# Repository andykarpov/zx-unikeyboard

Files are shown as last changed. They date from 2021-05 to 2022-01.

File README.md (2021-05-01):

# zx-unikeyboard-ps2

This is a ps/2 keyboard controller that allows to connect any keyboard matrix and remap its keys into a ps/2 keyboard.

Based on zx-unikeyboard controller 
https://github.com/valerium-labs/zx-unikeyboard 

Based on ideas of converting a custom keyboard into PS/2-keyboard https://zx-pk.ru/threads/32497-kak-peredelat-prakticheski-lyubuyu-klaviaturu-v-ps-2.html 
and PS/2-CPLD-keyboard controller by andykarpov https://github.com/andykarpov/ps2_cpld_kbd

Unikeyboard ps/2 controller lets you connect any laptop or desktop keyboard matrix (up to 26 pins in any order), 
scan its keypresses to collect the pins interaction (AVR-Keyexplorer module), build an array of its keys and then "learn" 
a controller firmware (avr_kbd_ps2) to convert your keyboard layout into standard ps/2 keyboard.

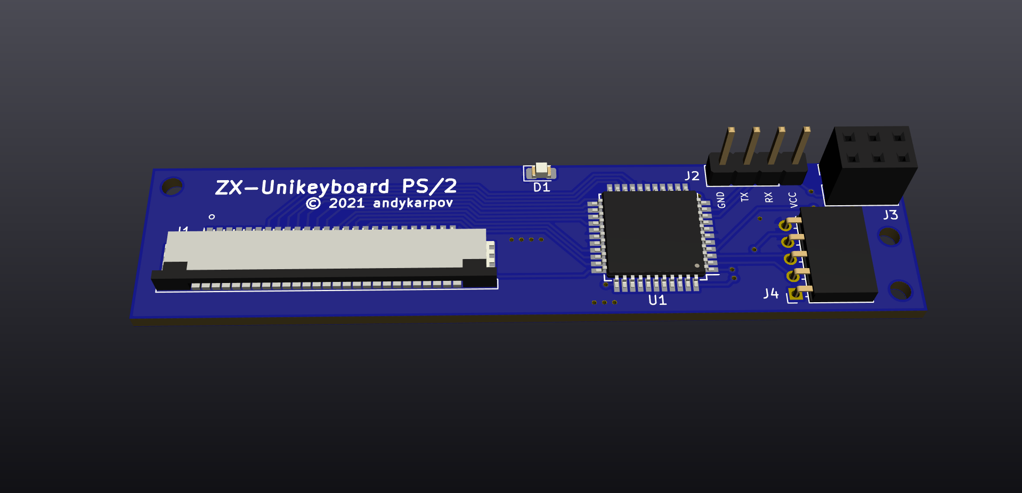
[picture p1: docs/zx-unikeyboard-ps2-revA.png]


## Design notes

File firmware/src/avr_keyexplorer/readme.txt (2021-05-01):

This is and AVR firmware source code for "Unikeyboard explorer" (keyboard matrix scanning software).
Scans any keyboard and generates the debug output on UART for col/row of key pressed.

Atmega32-16AU, 8Mhz internal clock

Designed for custom keyboard matrix by Valeriy Matveyev
valerium@rambler.ru
Russia, 2021

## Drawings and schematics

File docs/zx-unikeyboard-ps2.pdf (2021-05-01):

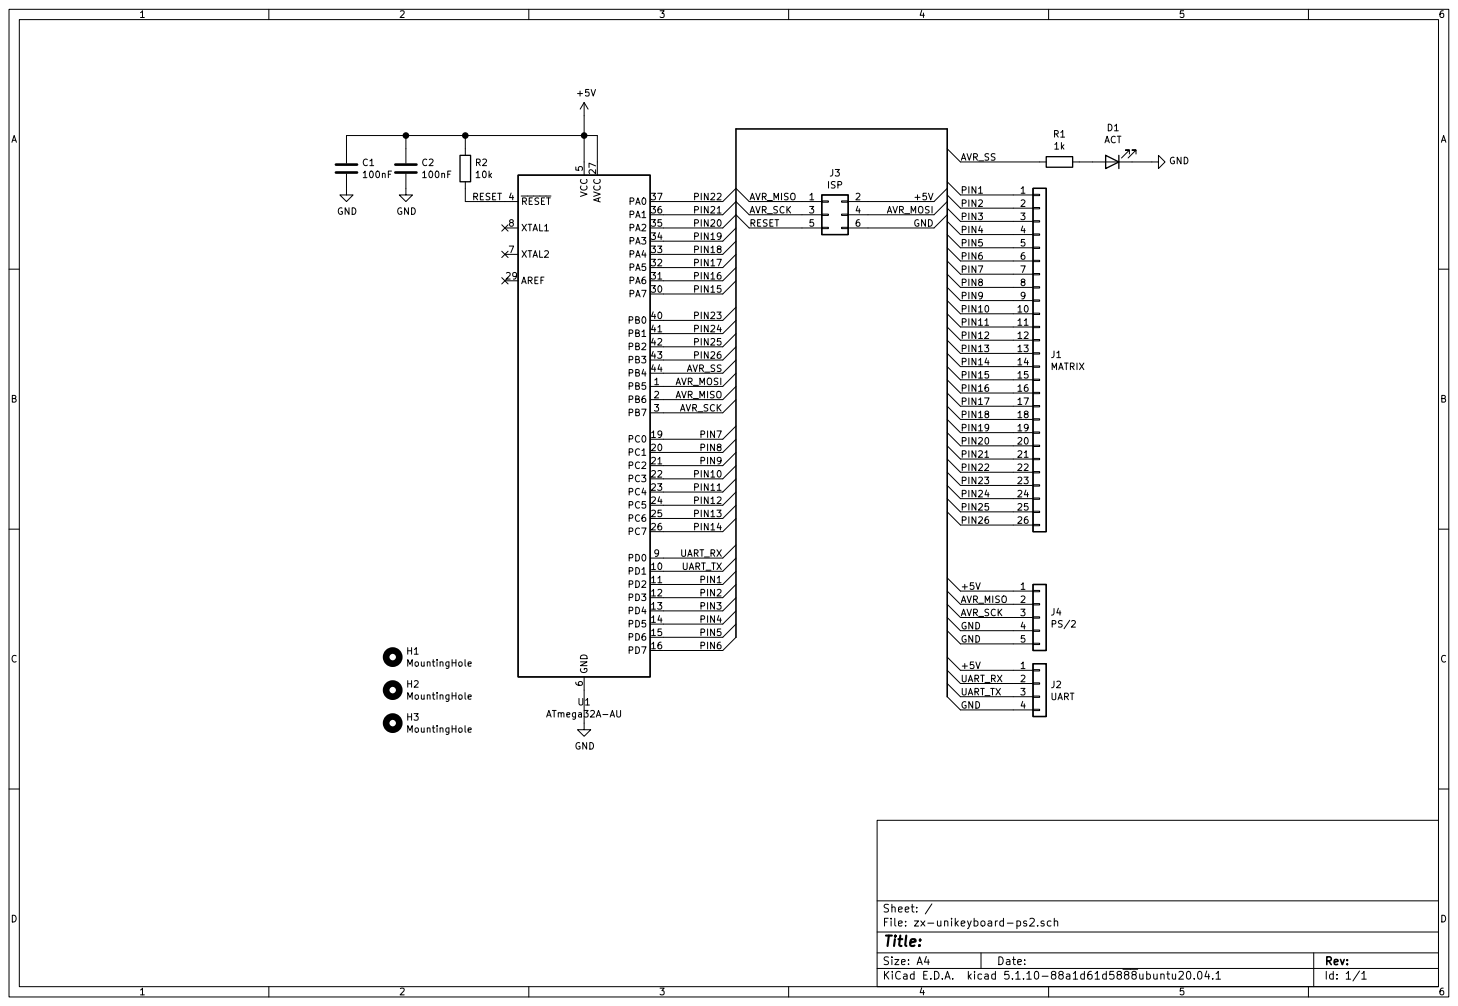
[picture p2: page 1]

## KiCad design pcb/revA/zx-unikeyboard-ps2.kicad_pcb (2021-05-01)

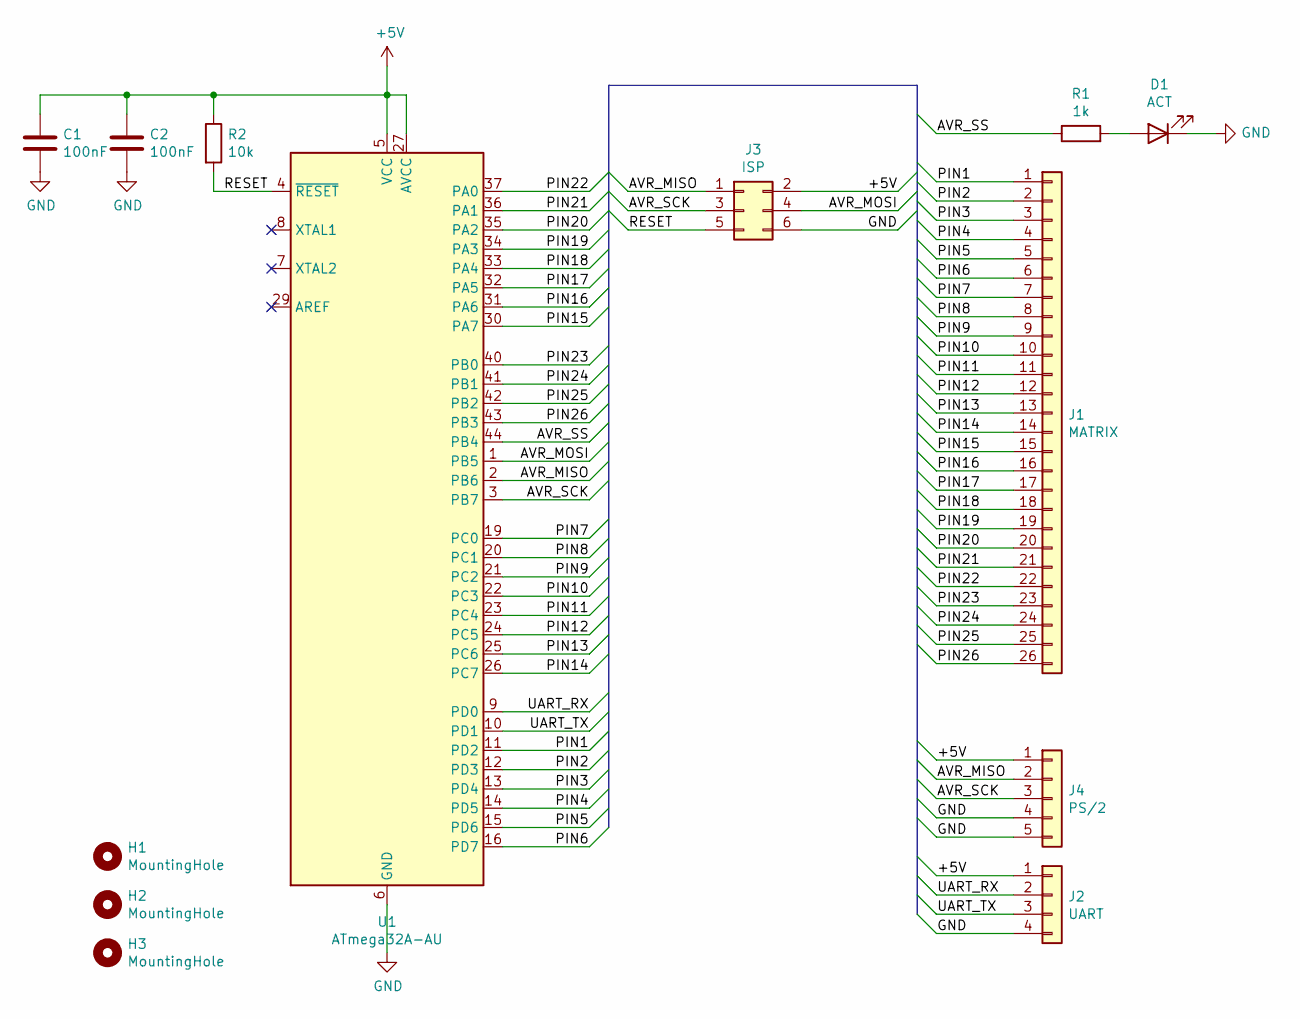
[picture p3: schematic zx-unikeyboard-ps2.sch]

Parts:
C1, C2: 100nF; C_0805_2012Metric_Pad1.18x1.45mm_HandSolder
D1: ACT; LED_0805_2012Metric_Pad1.15x1.40mm_HandSolder
H1, H2, H3: MountingHole; MountingHole_2.1mm
J1: MATRIX; TE_2-84952-6_1x26-1MP_P1.0mm_Horizontal
J2: UART; PinHeader_1x04_P2.54mm_Vertical
J3: ISP; PinSocket_2x03_P2.54mm_Vertical
J4: PS/2; JST_PH_S5B-PH-K_1x05_P2.00mm_Horizontal
R1: 1k; R_0805_2012Metric_Pad1.20x1.40mm_HandSolder
R2: 10k; R_0805_2012Metric_Pad1.20x1.40mm_HandSolder
U1: ATmega32A-AU; TQFP-44_10x10mm_P0.8mm

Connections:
+5V: C1.1, C2.1, J2.1, J3.2, J4.1, R2.1, U1.5 (VCC), U1.17 (VCC), U1.27 (AVCC), U1.38 (VCC)
/AVR_MISO: J3.1, J4.2, U1.2 (PB6)
/AVR_MOSI: J3.4, U1.1 (PB5)
/AVR_SCK: J3.3, J4.3, U1.3 (PB7)
/AVR_SS: R1.1, U1.44 (PB4)
/PIN1: J1.1, U1.11 (PD2)
/PIN2: J1.2, U1.12 (PD3)
/PIN3: J1.3, U1.13 (PD4)
/PIN4: J1.4, U1.14 (PD5)
/PIN5: J1.5, U1.15 (PD6)
/PIN6: J1.6, U1.16 (PD7)
/PIN7: J1.7, U1.19 (PC0)
/PIN8: J1.8, U1.20 (PC1)
/PIN9: J1.9, U1.21 (PC2)
/PIN10: J1.10, U1.22 (PC3)
/PIN11: J1.11, U1.23 (PC4)
/PIN12: J1.12, U1.24 (PC5)
/PIN13: J1.13, U1.25 (PC6)
/PIN14: J1.14, U1.26 (PC7)
/PIN15: J1.15, U1.30 (PA7)
/PIN16: J1.16, U1.31 (PA6)
/PIN17: J1.17, U1.32 (PA5)
/PIN18: J1.18, U1.33 (PA4)
/PIN19: J1.19, U1.34 (PA3)
/PIN20: J1.20, U1.35 (PA2)
/PIN21: J1.21, U1.36 (PA1)
/PIN22: J1.22, U1.37 (PA0)
/PIN23: J1.23, U1.40 (PB0)
/PIN24: J1.24, U1.41 (PB1)
/PIN25: J1.25, U1.42 (PB2)
/PIN26: J1.26, U1.43 (PB3)
/RESET: J3.5, R2.2, U1.4 (~RESET)
/UART_RX: J2.2, U1.9 (PD0)
/UART_TX: J2.3, U1.10 (PD1)
GND: C1.2, C2.2, D1.1 (K), J2.4, J3.6, J4.4, J4.5, U1.6 (GND), U1.18 (GND), U1.28 (GND), U1.39 (GND)
unnamed: D1.2 (A), R1.2

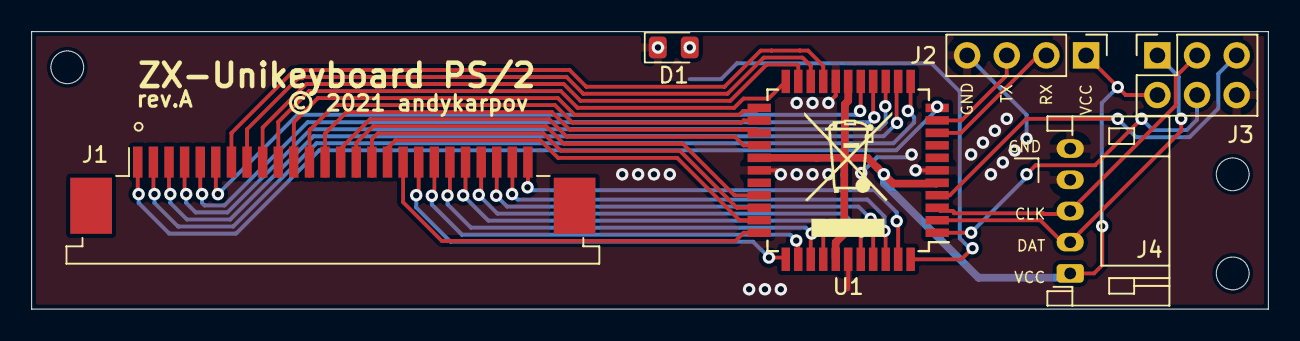
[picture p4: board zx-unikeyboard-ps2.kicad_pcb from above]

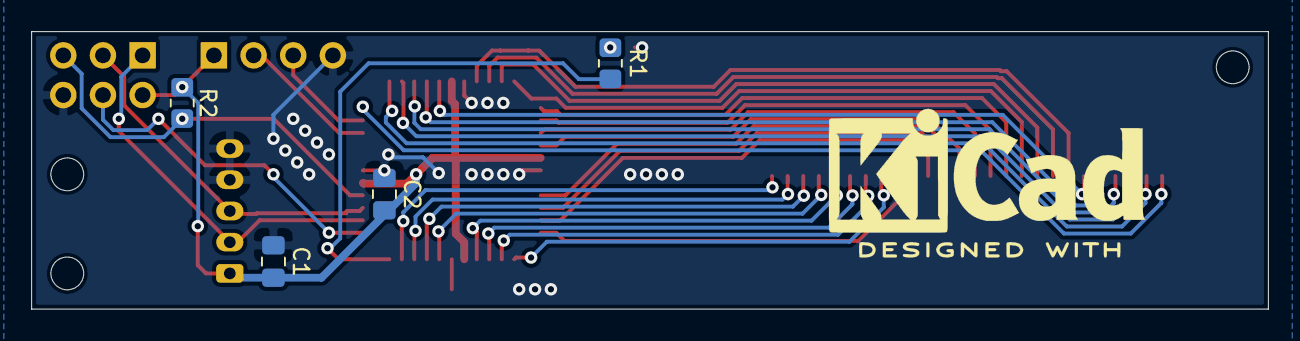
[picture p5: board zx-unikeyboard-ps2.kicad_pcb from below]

Board: 2 copper layers, 79.2 x 17.8 mm, 13 parts (4 on the bottom side), 36 nets.

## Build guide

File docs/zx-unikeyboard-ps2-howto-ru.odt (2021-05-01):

ZX-Unikeyboard PS/2

PS/2 контроллер и необходимое ПО для опроса и построения прошивку под произвольную клавиатурную матрицу до 26 пин.

valerum@rambler.ru

Russia, 2021

andy.karpov@gmail.com

Ukraine, 2021

Эта тема на форуме:

https://zx-pk.ru/threads/32497-kak-peredelat-prakticheski-lyubuyu-klaviaturu-v-ps-2/page8.html

# Краткий HOW-TO по настройке произвольной клавиатуры.

## Этап 1. Прошивка для опроса матрицы

Подключаем клавиатуру к атмеге (32, 16 или какой там захочется - главное, чтоб было как минимум четыре 8-разрядных порта) и собираем под нее avr-keyexplorer.ino в Arduino IDE.

Если нет поддержки нужного контроллера, ставим его, например, из модуля MightyCore через менеджере плат - https://mcudude.github.io/MightyCore/package_MCUdude_MightyCore_index.json), как добавить в менеджер плат - читать здесь: https://alexgyver.ru/lessons/naked-chip/.

Обращаем внимание на установку частоты 8 МГц в IDE при сборке прошивки, а также на установку соответствующих фьюзов (LOW=0x04, HIGH=0xD7 – важно получить 8 МГц на внутреннем генераторе). В случае других частот/вариантов тактирования правим то и другое единообразно.

Если есть отклонения от схемы в подключении пинов клавиатурного разъема к атмеге - приводим в соответствие все #define PIN* в скетче.

Прошиваем сборку «тестовой» прошивки в атмегу своим любимым программатором и соответствующим софтом.

## Этап 2. Тестирование опроса матрицы

Подключаем UART атмеги к ПК через любой удобный преобразователь, смотрим дебаг с соответствующего компорта в режиме 115200 8-n-1, можно пользоваться прилагаемой программой PortMon, можно встроенным монитором ком-порта в Arduino IDE. Нажимаем все клавиши своей клавиатуры, они все должны генерировать нажатия с парой чисел в дебаговом выводе - это номера пары пинов для каждой клавиши.

## Этап 3. Шаблон матрицы клавиатуры

Подготавливаем файл клавиатурного шаблона — это текстовый файл с именами всех имеющихся клавиш по одному в каждой строке (допускаются цифры и буквы латиницы, а также знаки «-» и «_»; прочие символы в именах могут вызвать ошибки компиляции прошивки на следующих этапах).

Для анализа рекомендуется внести ВСЕ клавиши, а не только предполагаемые к использованию, иначе может некорректно пройти анализ столбцов и строк и останутся непривязанные клавиши. Лучше вносить их не в алфавитном порядке, а в соответствии с расположением на клавиатуре (например, слева направа и сверху вниз).

Можно отредактировать имеющийся шаблон из двух приложенных (Asus X200 – 82 клавиши без кейпада, Asus X551 – 102 клавиши с кейпадом, но без выделенного Insert).

## Этап 4. Опрос и анализ матрицы

Запускаем UniKeyboardConf_en.exe (или .._ru.exe), выбираем COM-порт, куда подключен UART для атмеги, в режиме 115200 8-n-1 (остальные параметры не важны).

При необходимости можно отредактировать файл клавиатурного шаблона — Edit Keyboard template (из программы вызывается notepad для его редактирования), сохраняем.

Загружаем файл шаблона (Open Keyboard Template), удостоверяемся, что считано нужное количество клавиш. Запускаем считывание (Start reading keys), нажимаем все клавиши в соответствии с подсказками; если произошла ошибка — можно заново начать считывание кнопкой «Start reading keys».

По завершении считывания всех клавиш из списка будет предложено начать анализ данных («Would you like to analyze...»), после завершения анализа будет дан комментарий по результату, построен и предложен к сохранению файл customkey.h. Его следует сохранить в каталог с прошивкой avr_kbd_ps2/includes/.

В результате анализа будут получены два непересекающихся множества линий клавиатуры — продолжных и поперечных. Те, что в меньшем количестве, будут далее считаться столбцами, остальные — строками. В файле customkey.h будут включены все определения имен клавиш с префиксом KEY_, массив соответствующих им линий и два массива с номерами линий-столбцов (cols) и линий-строк (rows).

Внимание! Если после анализа выдается предупреждение о том, что остались неприсвоенные строки/столбцы так как в паре строка/столбец оказалась всего одна клавиша, нужно проанализировать, что это за клавиши и не было ли ошибок ввода. Если указанные кавиши не планируется использовать на Спеке, то можно не обращать внимания на это предупреждение — в файл customkey.h они не будут включены.

## Этап 5. Сборка основной прошивки

Ревизируем исходный код основной прошивки avr_kbd_ps2 на предмет соответствия имен клавиш в кейсах внутри функции kbd_event тому, что сформировано в customkey.h, добиваемся отстутствия ошибок компиляции, если нужно – корректируем обработку нужных клавиш. Собираем прошивку, загружаем ее в Atmega.

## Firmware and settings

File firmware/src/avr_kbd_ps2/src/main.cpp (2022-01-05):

/*
 * This is an AVR firmware source code for ZX Unikeyboard PS/2 controller.
 * Needs to be recompiled for any keyboard after building your own customkey.h with ZX Unikeyboard configuration tool
 * 
 * Based on AVR keyboard firmware for ps2_cpld_kbd project
 * @author Andy Karpov <andy.karpov@gmail.com>
 * Ukraine, 2019
 * 
 * Ported to ATMega32 and redesigned for custom keyboard matrix by Valeriy Matveyev
 * valerium@rambler.ru
 * Russia, 2021
 * 
 * Added PS/2 output (PB6, PB7) instead of CPLD via SPI, moved to the platformio rails by:
 * andy.karpov@gmail.com
 * Ukraine, 2021 
 */

#include <Arduino.h>
#include "config.h"
#include "customkey.h"
#include "ps2dev.h"

//MCU pins array to search by keyboard pin number
const uint8_t pins[] = {
  0xFF, IO1, IO2, IO3, IO4, IO5, IO6, IO7, IO8, IO9, IO10,
  IO11, IO12, IO13, IO14, IO15, IO16, IO17, IO18, IO19, IO20,
  IO21, IO22, IO23, IO24, IO25, IO26
};

uint8_t keyaddr_mapped[COLS_MAX][ROWS_MAX]; // mapped keyaddr array by col/row indicies
bool matrix[MATRIX_SIZE]; // matrix of pressed keys

PS2dev kbd(PIN_PB6, PIN_PB7);  // PS2dev object (PB6:data, PB7:clock)
unsigned long tl = 0; // last time led was blinked
bool is_fn = false; // is FN key pressed

// methods declaration
void clear_matrix(int clear_size);
void kbd_do(unsigned char code, bool state);
void kbd_do_special(unsigned char code, bool state);
void kbd_event(uint8_t key, bool state);
void setup_keyaddr_mapped();
void poll_matrix();
void setup();
void loop();

// clear the entire matrix of pressed keys
void clear_matrix(int clear_size)
{
    // release all keys
  for (int i=0; i<clear_size; i++) {
      matrix[i] = RELEASED;
  }
}

// press/release a normal key
void kbd_do(unsigned char code, bool state) {
  if (state) {
    kbd.keyboard_press(code); 
  } else {
    kbd.keyboard_release(code);
  }
}

// press/release a special key
void kbd_do_special(unsigned char code, bool state) {
  if (state) {
    kbd.keyboard_press_special(code);
  } else {
    kbd.keyboard_release_special(code);
  }
}

// trigger a ps/2 event for key with state
void kbd_event(uint8_t key, bool state)
{
#if DEBUG_MODE==1
  Serial.print(state ? F("Pressed key: ") : F("Released key: "));
  Serial.println(key, HEX);
#endif
  switch (key) 
  {
    case KEY_LSHIFT: kbd_do(kbd.ScanCodes::LEFT_SHIFT, state); break;
    case KEY_LCTRL: kbd_do(kbd.ScanCodes::LEFT_CONTROL, state); break;
    case KEY_RSHIFT: kbd_do(kbd.ScanCodes::RIGHT_SHIFT, state); break;
//    case KEY_RCTRL: kbd_do_special(kbd.SpecialScanCodes::RIGHT_CONTROL, state); break;
    case KEY_LALT: kbd_do(kbd.ScanCodes::LEFT_ALT, state); break;
    case KEY_RALT: kbd_do_special(kbd.SpecialScanCodes::RIGHT_ALT, state); break;
    case KEY_DELETE: kbd_do_special(kbd.SpecialScanCodes::DELETE, state); break;
    case KEY_INSERT: 
      if (state) {
        if (is_fn) {
          kbd.keyboard_press_printscreen();
        } else {
          kbd_do_special(kbd.SpecialScanCodes::INSERT, state); 
        }
      } else {
        kbd_do_special(kbd.SpecialScanCodes::INSERT, false); 
        kbd.keyboard_release_printscreen();
      }
    break;
    case KEY_ACCENT: kbd_do(kbd.ScanCodes::ACCENT, state); break;
    case KEY_UP: 
      if (state) {
        kbd_do_special(is_fn ? kbd.SpecialScanCodes::PAGE_UP : kbd.SpecialScanCodes::UP_ARROW, state); 
      } else {
        kbd_do_special(kbd.SpecialScanCodes::UP_ARROW, false);
        kbd_do_special(kbd.SpecialScanCodes::PAGE_UP, false);
      }
    break;
    case KEY_DOWN: 
      if (state) {
        kbd_do_special(is_fn ? kbd.SpecialScanCodes::PAGE_DOWN : kbd.SpecialScanCodes::DOWN_ARROW, state); 
      } else {
        kbd_do_special(kbd.SpecialScanCodes::DOWN_ARROW, false);
        kbd_do_special(kbd.SpecialScanCodes::PAGE_DOWN, false);
      }
    break;
    case KEY_LEFT: 
      if (state) {
        kbd_do_special(is_fn ? kbd.SpecialScanCodes::HOME : kbd.SpecialScanCodes::LEFT_ARROW, state); 
      } else {
        kbd_do_special(kbd.SpecialScanCodes::LEFT_ARROW, false);
        kbd_do_special(kbd.SpecialScanCodes::HOME, false);
      }
    break;
    case KEY_RIGHT: 
      if (state) {
        kbd_do_special(is_fn ? kbd.SpecialScanCodes::END : kbd.SpecialScanCodes::RIGHT_ARROW, state); 
      } else {
        kbd_do_special(kbd.SpecialScanCodes::RIGHT_ARROW, false);
        kbd_do_special(kbd.SpecialScanCodes::END, false);
      }
    break;
    case KEY_ESC: kbd_do(kbd.ScanCodes::ESCAPE, state); break;
    case KEY_BACKSPACE: kbd_do(kbd.ScanCodes::BACKSPACE, state); break;
    case KEY_ENTER: kbd_do(kbd.ScanCodes::ENTER, state); break;
    case KEY_SPACE: kbd_do(kbd.ScanCodes::SPACE, state); break;
    case KEY_TAB: kbd_do(kbd.ScanCodes::TAB, state); break;
    case KEY_FN: is_fn = state; break;

    // Letters & numbers
    case KEY_A: kbd_do(kbd.ScanCodes::A, state); break;
    case KEY_B: kbd_do(kbd.ScanCodes::B, state); break;
    case KEY_C: kbd_do(kbd.ScanCodes::C, state); break;
    case KEY_D: kbd_do(kbd.ScanCodes::D, state); break;
    case KEY_E: kbd_do(kbd.ScanCodes::E, state); break;
    case KEY_F: kbd_do(kbd.ScanCodes::F, state); break;
    case KEY_G: kbd_do(kbd.ScanCodes::G, state); break;
    case KEY_H: kbd_do(kbd.ScanCodes::H, state); break;
    case KEY_I: kbd_do(kbd.ScanCodes::I, state); break;
    case KEY_J: kbd_do(kbd.ScanCodes::J, state); break;
    case KEY_K: kbd_do(kbd.ScanCodes::K, state); break;
    case KEY_L: kbd_do(kbd.ScanCodes::L, state); break;
    case KEY_M: kbd_do(kbd.ScanCodes::M, state); break;
    case KEY_N: kbd_do(kbd.ScanCodes::N, state); break;
    case KEY_O: kbd_do(kbd.ScanCodes::O, state); break;
    case KEY_P: kbd_do(kbd.ScanCodes::P, state); break;
    case KEY_Q: kbd_do(kbd.ScanCodes::Q, state); break;
    case KEY_R: kbd_do(kbd.ScanCodes::R, state); break;
    case KEY_S: kbd_do(kbd.ScanCodes::S, state); break;
    case KEY_T: kbd_do(kbd.ScanCodes::T, state); break;
    case KEY_U: kbd_do(kbd.ScanCodes::U, state); break;
    case KEY_V: kbd_do(kbd.ScanCodes::V, state); break;
    case KEY_W: kbd_do(kbd.ScanCodes::W, state); break;
    case KEY_X: kbd_do(kbd.ScanCodes::X, state); break;
    case KEY_Y: kbd_do(kbd.ScanCodes::Y, state); break;
    case KEY_Z: kbd_do(kbd.ScanCodes::Z, state); break;

    // digits
    case KEY_0: kbd_do(kbd.ScanCodes::ZERO, state); break;
    case KEY_1: kbd_do(kbd.ScanCodes::ONE, state); break;
    case KEY_2: kbd_do(kbd.ScanCodes::TWO, state); break;
    case KEY_3: kbd_do(kbd.ScanCodes::THREE, state); break;
    case KEY_4: kbd_do(kbd.ScanCodes::FOUR, state); break;
    case KEY_5: kbd_do(kbd.ScanCodes::FIVE, state); break;
    case KEY_6: kbd_do(kbd.ScanCodes::SIX, state); break;
    case KEY_7: kbd_do(kbd.ScanCodes::SEVEN, state); break;
    case KEY_8: kbd_do(kbd.ScanCodes::EIGHT, state); break;
    case KEY_9: kbd_do(kbd.ScanCodes::NINE, state); break;

    // Others
    case KEY_CAPSLOCK: kbd_do(kbd.ScanCodes::CAPS_LOCK, state); break;
    case KEY_EQUAL: kbd_do(kbd.ScanCodes::EQUAL, state); break;
    case KEY_MINUS: kbd_do(kbd.ScanCodes::MINUS, state); break;
    case KEY_LBRACKET: kbd_do(kbd.ScanCodes::OPEN_BRACKET, state); break;
    case KEY_RBRACKET: kbd_do(kbd.ScanCodes::CLOSE_BRACKET, state); break;
    case KEY_COMMA: kbd_do(kbd.ScanCodes::COMMA, state); break;
    case KEY_PERIOD: kbd_do(kbd.ScanCodes::PERIOD, state); break;
    case KEY_SEMICOLON: kbd_do(kbd.ScanCodes::SEMI_COLON, state); break;
    case KEY_QUOTE: kbd_do(kbd.ScanCodes::TICK_MARK, state); break;
    case KEY_SLASH: kbd_do(kbd.ScanCodes::SLASH, state); break;
    case KEY_BACKSLASH: kbd_do(kbd.ScanCodes::BACKSLASH, state); break;
//    case KEY_PRTSCR: if (state) { kbd.keyboard_press_printscreen(); } else { kbd.keyboard_release_printscreen(); } break;
    case KEY_PAUSE: if (state) kbd.keyboard_pausebreak(); break;
    case KEY_CONTEXTMENU: kbd_do_special(kbd.SpecialScanCodes::MENUS, state); break;

    // F keys
    case KEY_F1: kbd_do(kbd.ScanCodes::F1, state); break;
    case KEY_F2: kbd_do(kbd.ScanCodes::F2, state); break;
    case KEY_F3: kbd_do(kbd.ScanCodes::F3, state); break;
    case KEY_F4: kbd_do(kbd.ScanCodes::F4, state); break;
    case KEY_F5: kbd_do(kbd.ScanCodes::F5, state); break;
    case KEY_F6: kbd_do(kbd.ScanCodes::F6, state); break;
    case KEY_F7: kbd_do(kbd.ScanCodes::F7, state); break;
    case KEY_F8: kbd_do(kbd.ScanCodes::F8, state); break;
    case KEY_F9: kbd_do(kbd.ScanCodes::F9, state); break;
    case KEY_F10: kbd_do(kbd.ScanCodes::F10, state); break;
    case KEY_F11: 
      if (state) {
        kbd_do(is_fn ? kbd.ScanCodes::NUM_LOCK : kbd.ScanCodes::F11, state);
      } else {
        kbd_do(kbd.ScanCodes::F11, false);        
        kbd_do(kbd.ScanCodes::NUM_LOCK, false);
      }
    break;
    case KEY_F12: 
      if (state) {
        kbd_do(is_fn ? kbd.ScanCodes::SCROLL_LOCK : kbd.ScanCodes::F12, state);
      } else {
        kbd_do(kbd.ScanCodes::F12, false);        
        kbd_do(kbd.ScanCodes::SCROLL_LOCK, false);
      }
    break;
  }
}

// setup indexed keyaddr_mapped array by col/row indicies
void setup_keyaddr_mapped()
{
  for(uint8_t i = 0; i < sizeof(keyaddr)/3; i++) {
    uint8_t col = 0;
    uint8_t row = 0;
    // thekey
    uint8_t thekey = keyaddr[i][0];
    // find col index
    for (uint8_t j=0; j<COLS_MAX; j++) {
      if ((keyaddr[i][1] == cols[j]) || (keyaddr[i][2] == cols[j])) {
        col = j;
      }
    }
    // find row index
    for (uint8_t j=0; j<ROWS_MAX; j++) {
      if ((keyaddr[i][1] == rows[j]) || (keyaddr[i][2] == rows[j])) {
        row = j;
      }
    }
    keyaddr_mapped[col][row] = thekey;
  }
}

// poll matrix 
void poll_matrix()
{
  uint8_t i, current_col, current_row, thekey;

  //all keys polling cycle
  for (current_col = 0; current_col < COLS_MAX; current_col++) {
    
    // set columns into Z state
    for (i = 0; i < COLS_MAX; i++) {
      pinMode(pins[cols[i]], INPUT_PULLUP);
    }

    // set current col to 0
    pinMode(pins[cols[current_col]], OUTPUT);
    digitalWrite(pins[cols[current_col]], LOW);
    
    // reading rows (pressed key = 0)
    for (current_row = 0; current_row < ROWS_MAX; current_row++) {

      thekey = keyaddr_mapped[current_col][current_row];

      uint8_t pin = pins[rows[current_row]];
      if (digitalRead(pin) == LOW) {
        // pressed key
        if ((matrix[thekey] != PRESSED)) {
            matrix[thekey] = PRESSED;
            // transmit press event
            kbd_event(thekey, PRESSED);
            tl = millis();
        }
      } else {
        // released key
        if ((matrix[thekey] != RELEASED)) {
            matrix[thekey] = RELEASED;
            // transmit release event
            kbd_event(thekey, RELEASED);
        }
      }
    }
  }
}

// initial setup
void setup()
{
#if DEBUG_MODE==1
  Serial.begin(115200);
  Serial.flush();
#endif

  pinMode(LED1, OUTPUT);
  digitalWrite(LED1, HIGH);

  for (uint8_t i=0; i<ROWS_MAX; i++) pinMode (pins[rows[i]], INPUT_PULLUP);
  for (uint8_t i=0; i<COLS_MAX; i++) pinMode (pins[cols[i]], INPUT_PULLUP); 

  // clear full matrix
  clear_matrix(MATRIX_SIZE);

  // setup keyaddr_mapped array
  setup_keyaddr_mapped();

#if DEBUG_MODE==1
  Serial.println(F("ZX unikeyboard PS/2 controller v1.0"));
#endif

  // send the keyboard start up
  kbd.keyboard_init();
}

// main loop
void loop()
{
  unsigned char leds = 0;

  // ps/2 keyboard handle every 10ms
  kbd.keyboard_handle(&leds);

  // poll matrix
  poll_matrix();  

  // control led1
  if (millis() - tl < 100) {
    digitalWrite(LED1, LOW);
  } else {
    digitalWrite(LED1, HIGH);
  }
}

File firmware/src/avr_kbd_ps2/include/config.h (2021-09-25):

#define DEBUG_MODE 0
#define PRESSED true
#define RELEASED false
#define MATRIX_SIZE 84

// Keyboard connector pins corresponding to MCU pins
// Using pin naming from the https://github.com/MCUdude/MightyCore core
#define IO1 PIN_PD2
#define IO2 PIN_PD3
#define IO3 PIN_PD4
#define IO4 PIN_PD5
#define IO5 PIN_PD6
#define IO6 PIN_PD7
#define IO7 PIN_PC0
#define IO8 PIN_PC1
#define IO9 PIN_PC2
#define IO10 PIN_PC3
#define IO11 PIN_PC4
#define IO12 PIN_PC5
#define IO13 PIN_PC6
#define IO14 PIN_PC7
#define IO15 PIN_PA7
#define IO16 PIN_PA6
#define IO17 PIN_PA5
#define IO18 PIN_PA4
#define IO19 PIN_PA3
#define IO20 PIN_PA2
#define IO21 PIN_PA1
#define IO22 PIN_PA0
#define IO23 PIN_PB0
#define IO24 PIN_PB1
#define IO25 PIN_PB2
#define IO26 PIN_PB3
#define LED1 PIN_PB4

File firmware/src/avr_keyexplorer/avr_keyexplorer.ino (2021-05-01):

/*
 * This is and AVR firmware source code for "Unikeyboard explorer" (keyboard matrix scanning software).
 * Scans any keyboard of up to 26 pins and generates the debug output on UART for col/row of key pressed.
 * 
 * Based on AVR keyboard firmware for ps2_cpld_kbd project
 * @author Andy Karpov <andy.karpov@gmail.com>
 * Ukraine, 2019
 * 
 * Ported to ATMega32 and redesigned for custom keyboard matrix by Valeriy Matveyev
 * valerium@rambler.ru
 * Russia, 2021
 * 
 */

#define PINS_MAX 26

#define PIN1 PIN_PD2
#define PIN2 PIN_PD3
#define PIN3 PIN_PD4
#define PIN4 PIN_PD5
#define PIN5 PIN_PD6
#define PIN6 PIN_PD7
#define PIN7 PIN_PC0
#define PIN8 PIN_PC1
#define PIN9 PIN_PC2
#define PIN10 PIN_PC3
#define PIN11 PIN_PC4
#define PIN12 PIN_PC5
#define PIN13 PIN_PC6
#define PIN14 PIN_PC7
#define PIN15 PIN_PA7
#define PIN16 PIN_PA6
#define PIN17 PIN_PA5
#define PIN18 PIN_PA4
#define PIN19 PIN_PA3
#define PIN20 PIN_PA2
#define PIN21 PIN_PA1
#define PIN22 PIN_PA0
#define PIN23 PIN_PB0
#define PIN24 PIN_PB1
#define PIN25 PIN_PB2
#define PIN26 PIN_PB3

const uint8_t pins[PINS_MAX] = 
{
  PIN1, PIN2, PIN3, PIN4, PIN5, PIN6, PIN7, PIN8, PIN9, PIN10, 
  PIN11, PIN12, PIN13, PIN14, PIN15, PIN16, PIN17, PIN18, PIN19, PIN20,
  PIN21, PIN22, PIN23, PIN24, PIN25, PIN26
};


// initial setup
void setup()
{
  for (uint8_t i=0; i<PINS_MAX; i++) pinMode (pins[i], INPUT_PULLUP);

  Serial.begin(115200);
  Serial.flush();
  Serial.println(F("Unikeyboard matrix explorer v1.0"));
}

// main loop
void loop()
{
  uint8_t colcount, rowcount;

  for (colcount=0; colcount<PINS_MAX; colcount++)
   {
     for (rowcount=0; rowcount<PINS_MAX; rowcount++) pinMode (pins[rowcount], INPUT_PULLUP);
     
     pinMode (pins[colcount], OUTPUT);
     digitalWrite (pins[colcount], LOW);
     
     for (rowcount=0; rowcount<PINS_MAX; rowcount++)
              if ( (rowcount != colcount) and !digitalRead(pins[rowcount]) )
                  {
                  Serial.println ("Pressed key ("+String((colcount<rowcount?colcount:rowcount)+1)+", "+String((colcount<rowcount?rowcount:colcount)+1)+")");
                  delay (300);
                  }
   }
}

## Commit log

2021-05-01 Added PS/2 version
    [matrix_x200.xls, zx-unikeyboard-ps2.kicad_pcb, zx-unikeyboard-ps2.sch]
2021-05-01 Small improvements to PCB rev.A
    [zx-unikeyboard-ps2.kicad_pcb, zx-unikeyboard-ps2.sch]
2021-09-25 Fixed ESC, added INS key emulation on Fn+Del
    [config.h, main.cpp]
2021-12-20 Updated release with fixed ESC and other improvements
2022-01-05 Hotfix ESC, pause/break

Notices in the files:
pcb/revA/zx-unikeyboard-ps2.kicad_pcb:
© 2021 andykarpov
